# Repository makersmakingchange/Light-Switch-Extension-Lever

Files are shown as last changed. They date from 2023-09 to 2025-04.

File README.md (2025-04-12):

# Light Switch Extension Lever
The Light Switch Extension Lever is a lever designed to extend the toggle on a light switch. For some users with arthritis, limited grip strength or finger dexterity, it can be difficult to use a light switch. The Light Switch Extension Lever allows the user to flip the switch without needing any grip strength or nearly as much precision.

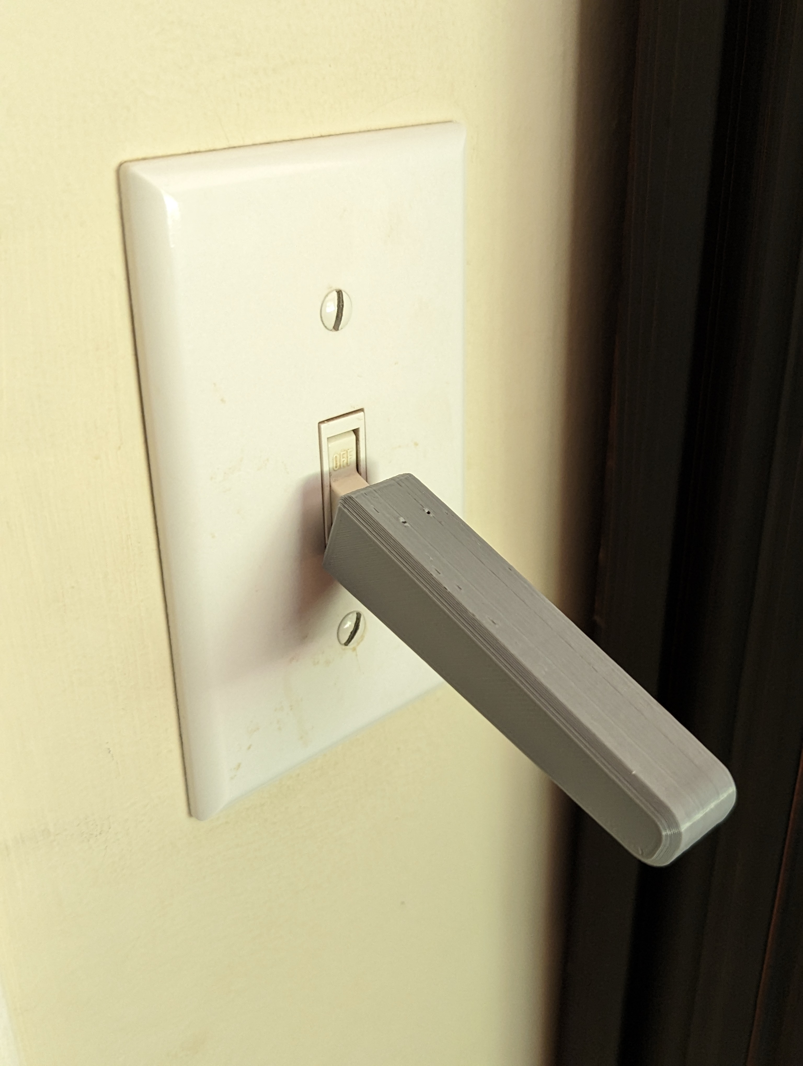
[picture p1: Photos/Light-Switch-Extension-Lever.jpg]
Picture of Light Switch Extension Lever.


## More info at
- [Makers Making Change Project Page](https://makersmakingchange.com/project/light-switch-extension-lever/)

## How to Obtain a Light Switch Extension Lever
### 1. Do it Yourself (DIY) or Do it Together (DIT)

This is an open-source assistive technology, so anyone is free to build it. All of the files and instructions required to build the device are contained within this repository. Refer to the Maker Guide below.

### 2. Request a build of this device

If you would like to obtain a Light Switch Extension Lever, you may submit a build request through the [MMC Library Page](https://makersmakingchange.com/project/light-switch-extension-lever/). The requestor is responsible for the cost of materials and any shipping.

### 3. How to build this device for someone else

If you have the skills and equipment to build this device, and would like to donate your time to create the switch for someone who needs it, visit the [MMC Maker Wanted](https://makersmakingchange.com/maker-wanted/) section.

## Getting Started

### 1. Read through the Maker Guide

The Maker Guide outlines all the different instructions for creating the device.

### 2. Print the 3D Printable components

All of the files and individual print files can be in the [/Build_Files/3D_Printing_Files](/Build_Files/3D_Printing_Files/) folder.

### 3. Assemble the Light Switch Extension Lever

Reference the [User Guide](/Documentation/Light_Switch_Extension_Lever_User_Guide_V1.0.pdf) for the tools and steps required to build each portion.

## Files
### Documentation
| Document | Version | Link |
|---|---|---|
| Design Rationale | 1.0 | [Light_Switch_Extension_Lever_Design_Rationale](/Documentation/Light_Switch_Extension_Lever_Design_Rationale_V1.0.pdf) |
| Maker Checklist | 1.0 | [Light_Switch_Extension_Lever_Maker_Checklist](/Documentation/Light_Switch_Extension_Lever_Maker_Checklist_V1.0.pdf) |
| Bill of Materials | 1.0 | [Light_Switch_Extension_Lever_Bill_of_Materials](/Documentation/Light_Switch_Extension_Lever_BOM_V1.0.xlsx) |
| 3D Printing Guide | 1.0 | [Light_Switch_Extension_Lever_3D_Printing_Guide](/Documentation/Light_Switch_Extension_Lever_3D_Printing_Guide_V1.0.pdf) |
| User Guide | 1.0 | [Light_Switch_Extension_Lever_User_Guide](/Documentation/Light_Switch_Extension_Lever_User_Guide_V1.0.pdf) |
| Changelog | 1.0 | [Light_Switch_Extension_Lever_Changelog](/Documentation/Light_Switch_Extension_Lever_Changelog_V1.0.pdf) |

### Design Files
 - [CAD Files](/Design_Files)

### Build Files
 - [3D Printing Files](/Build_Files/3D_Printing_Files)

## Attribution
Designers:
 - Initial Design by [Devon Smith](https://www.myminifactory.com/users/Devon_Smith) on [MyMiniFactory](https://www.myminifactory.com/object/3d-print-77490#google_vignette) and made available using a MyMiniFactory-Credit-Remix-Noncommercial license.
 - Further Design and Documentation by Neil Squire Society/Makers Making Change

## License
Everything needed or used to design, make, test, or prepare the Light Switch Extension Lever is licensed under the [MyMiniFactory - Credit - Remix - Noncommercial](https://www.myminifactory.com/object-licensing).

Accompanying material such as instruction manuals, videos, and other copyrightable works that are useful but not necessary to design, make, test, or prepare the Light Switch Extension Lever are published under a Creative Commons Attribution-ShareAlike 4.0 license https://creativecommons.org/licenses/by-sa/4.0/ (CC BY-SA 4.0).

---

<!-- ABOUT MMC START -->
## About Makers Making Change
[Makers Making Change Logo](https://www.makersmakingchange.com/)

Makers Making Change is a program of [Neil Squire](https://www.neilsquire.ca/), a Canadian non-profit that uses technology, knowledge, and passion to empower people with disabilities.

Makers Making Change leverages the capacity of community based Makers, Disability Professionals and Volunteers to develop and deliver affordable Open Source Assistive Technologies.

 - Website: [www.MakersMakingChange.com](https://www.makersmakingchange.com/)
 - GitHub: [makersmakingchange](https://github.com/makersmakingchange)
 - Bluesky: [@makersmakingchange.bsky.social](https://bsky.app/profile/makersmakingchange.bsky.social)
 - Instagram: [@makersmakingchange](https://www.instagram.com/makersmakingchange)
 - Facebook: [makersmakechange](https://www.facebook.com/makersmakechange)
 - LinkedIn: [Neil Squire Society](https://www.linkedin.com/company/neil-squire-society/)
 - Thingiverse: [makersmakingchange](https://www.thingiverse.com/makersmakingchange/about)
 - Printables: [MakersMakingChange](https://www.printables.com/@MakersMakingChange)

### Contact Us
For technical questions, to get involved, or to share your experience we encourage you to [visit our website](https://www.makersmakingchange.com/) or [contact us](https://www.makersmakingchange.com/s/contact).
<!-- ABOUT MMC END -->

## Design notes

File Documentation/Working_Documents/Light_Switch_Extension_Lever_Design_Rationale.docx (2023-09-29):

# Introduction

For some users with arthritis, limited grip strength or finger dexterity, it can be difficult to use a light switch. The Light Switch Extension Lever allows the user to flip the switch without needing any grip strength or nearly as much precision.

# Research

Name | Photo | Price | Link

Commercial

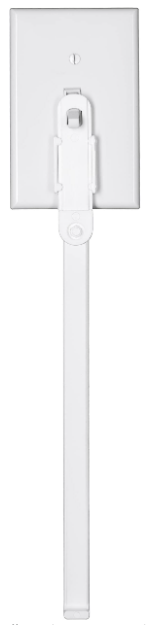
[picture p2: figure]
Amazon product image of the light switch extender for children

Light Switch Extender for Children | | $15.95 | Link (https://www.amazon.ca/Light-Switch-Extender-Children-PACK/dp/B01HHQRH96)

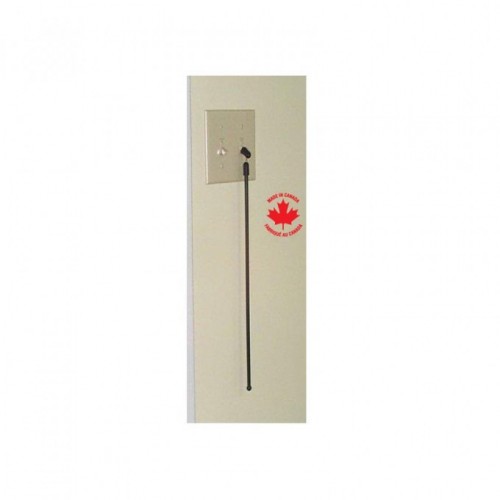
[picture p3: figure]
Image of the Light Switch Extender on a yellow white background, with a maple leaf on the wall

Light Switch Extender | | N/A | Link (https://ontariohomehealth.ca/light-switch-extender-16h165)

DIY

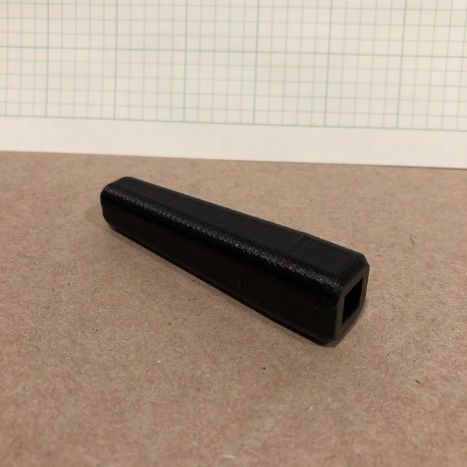
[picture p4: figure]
Light Switch Extension Lever image

Light Switch Extension Lever | | N/A | Link (https://www.myminifactory.com/object/3d-print-77490)

# Requirements

## Goals

G01 | Extend the toggle lever of a light switch so it can be toggled by bumping it with the hand

## Functional Requirements

F01 | Device must work, or be easily customizable to work with multiple thicknesses of light switch toggles

## Constraints

C01 | Must be entirely 3D printed

# Testing

The original design was tested, and found to require supports, and was too big for most of the light switches tried. It was remodeled in Fusion 360, with a changeable user parameter to accommodate any light switch.

# Opportunities for Improvement

Design could be altered to include a spring or some mechanism that would allow a one size fits all, instead of changing the Switch_Thickness parameter for each switch.

© 2023 by Neil Squire. This work is licensed under the CC BY SA 4.0 License: http://creativecommons.org/licenses/by-sa/4.0 Files available at https://github.com/makersmakingchange/light-switch-extension-lever/ Page 1 of 1

V1.0 | July 2023 Light Switch Extension Lever Design Rationale

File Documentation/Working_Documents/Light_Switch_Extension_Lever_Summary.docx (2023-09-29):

# Title

Light Switch Extension Lever

## Subtitle

The Light Switch Extension Lever allows the user to flip a light switch without needing any grip strength or nearly as much precision.

## Device Details

### Overview

For some users with arthritis, limited grip strength or finger dexterity, it can be difficult to use a light switch. The Light Switch Extension Lever allows the user to flip the switch without needing any grip strength or nearly as much precision.

### Usage

To use, place over the existing toggle switch on the light switch. The lever extends it and allows it to be bumped on and off with a hand or elbow. This works with all toggle style light switches that have a lever arm style toggle, as seen in the photo below.

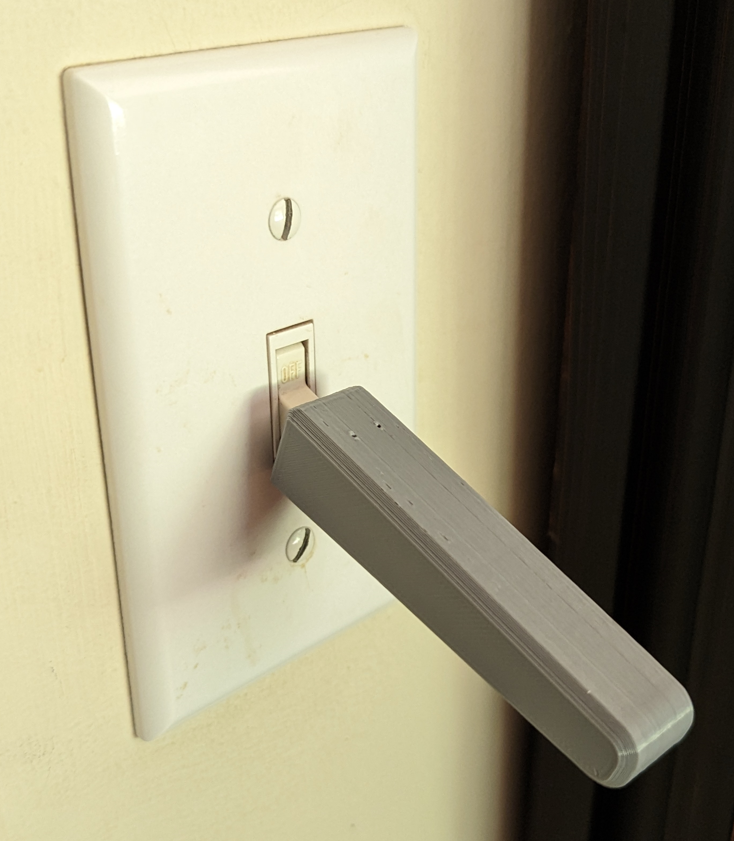
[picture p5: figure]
The light switch extender printed in grey attached to a light switch

### Cost

<$1.00

### Build Instructions

No build required, print and go.

#### Skills Required

-Basic 3D printing

#### Time Required

3D printing time: 1 hour 3 minutes

Assembly Time: <5 minutes

#### Tools

-3D printer

#### Components

-Light Switch Extension Lever.stl

### Attribution

- The Light Switch Extension Lever design (https://www.myminifactory.com/object/3d-print-77490) was created by Devon Smith (https://www.myminifactory.com/users/Devon_Smith) and made available using a MyMiniFactory-Credit-Remix-Noncommercial license.

-Further design and documentation by Neil Squire Society/Makers Making Change

© 2023 by Neil Squire. This work is licensed under the CC BY SA 4.0 License: http://creativecommons.org/licenses/by-sa/4.0 Files available at https://github.com/makersmakingchange/light-switch-extension-lever/ Page 1 of 1

V1.0 | July 2023 Light Switch Extension Lever Summary

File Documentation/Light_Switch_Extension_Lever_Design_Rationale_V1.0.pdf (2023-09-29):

V1.0 | July 2023

## Light Switch Extension Lever

## DESIGN RATIONALE

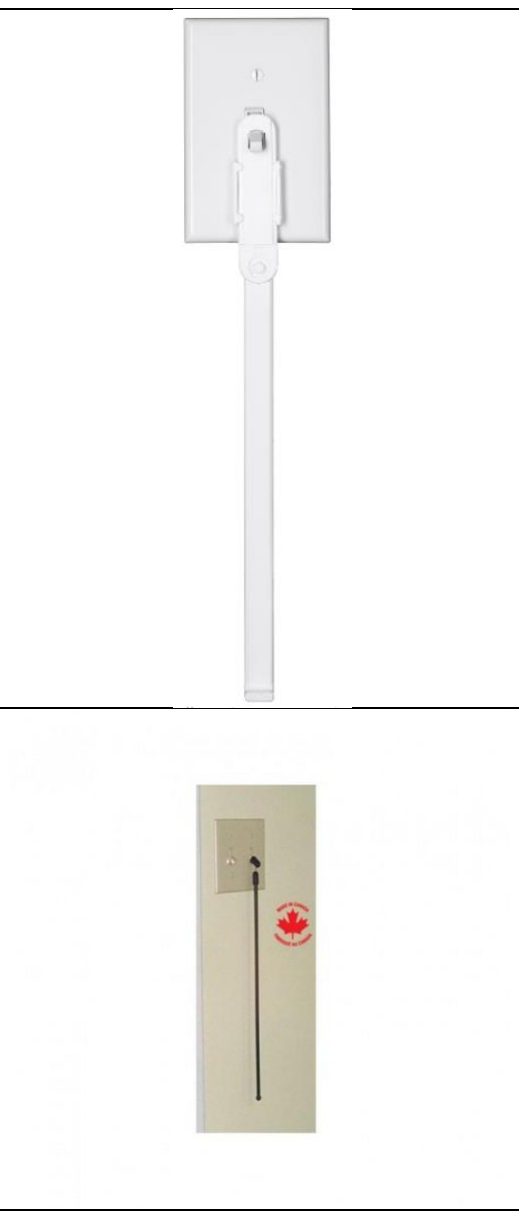
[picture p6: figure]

© 2023 by Neil Squire. (https://neilsquire.ca/)
This work is licensed under the CC BY SA 4.0 License: http://creativecommons.org/licenses/by-sa/4.0
Files available at https://github.com/makersmakingchange/light-switch-extension-lever/ | Page 1 of 2

### Introduction

For some users with arthritis, limited grip strength or finger dexterity, it can be difficult to use a light switch. The Light Switch Extension Lever allows the user to flip the switch without needing any grip strength or nearly as much precision.

### Research

Name | Photo | Price | Link
Commercial
Light Switch Extender for Children | $15.95 | Link (https://www.amazon.ca/Light-Switch-Extender-Children-PACK/dp/B01HHQRH96)
Light Switch Extender | N/A | Link (https://ontariohomehealth.ca/light-switch-extender-16h165)

DIY

V1.0 | July 2023

## Light Switch Extension Lever

## DESIGN RATIONALE

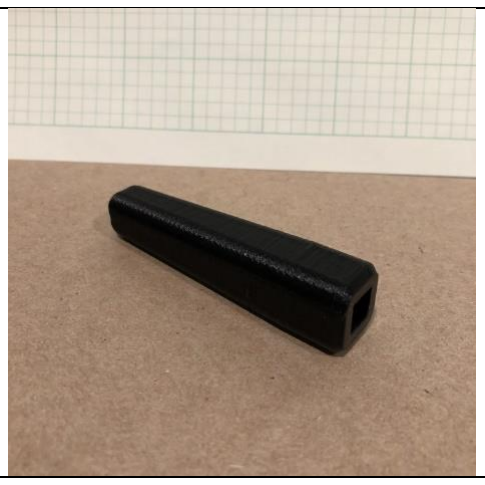
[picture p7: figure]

© 2023 by Neil Squire. (https://neilsquire.ca/)
This work is licensed under the CC BY SA 4.0 License: http://creativecommons.org/licenses/by-sa/4.0
Files available at https://github.com/makersmakingchange/light-switch-extension-lever/ | Page 2 of 2

Light Switch
Extension Lever
N/A | Link (https://www.myminifactory.com/object/3d-print-77490#google_vignette)

### Requirements

### Goals

G01 Extend the toggle lever of a light switch so it can be toggled by bumping it with the hand

### Functional Requirements

F01 Device must work, or be easily customizable to work with multiple thicknesses of light switch toggles

### Constraints

C01 Must be entirely 3D printed

### Testing

The original design was tested, and found to require supports, and was too big for most of the light switches tried. It was remodeled in Fusion 360, with a changeable user parameter to accommodate any light switch.

### Opportunities for Improvement

Design could be altered to include a spring or some mechanism that would allow a one size fits all, instead of changing the Switch_Thickness parameter for each switch.

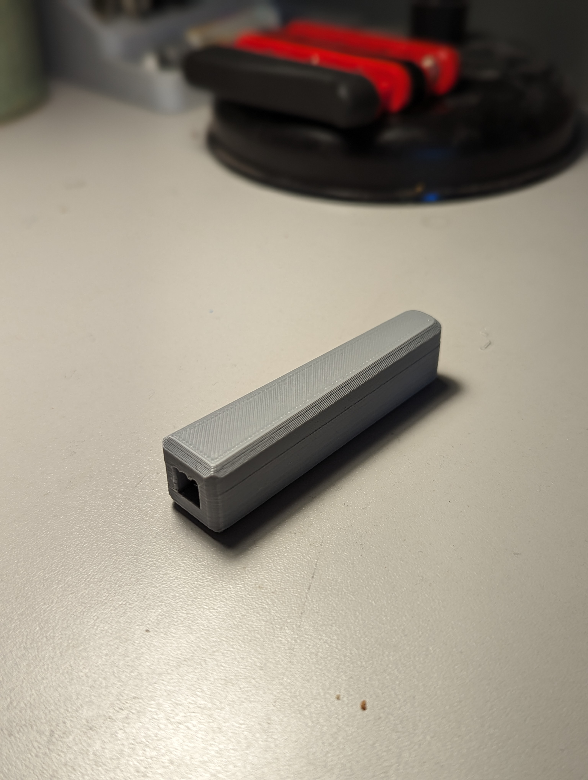
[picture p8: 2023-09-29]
Photos/Light Switch Extension Lever.stl.jpg

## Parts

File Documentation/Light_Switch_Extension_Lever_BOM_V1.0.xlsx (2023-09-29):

Light Switch Extension Lever |  | Total Cost | Total Print time (hr) | Total filament (g)
Version: V1.0 | Last Updated: 2023-Sep-18 | $0.27 | 0.00 | 9
Commercial Parts:
Part type (Electrical. Mechanical, Sanitization, ect) | Part Name | Quantity Needed | Pkg Quantity | Price per package | Price per Unit | Price for qty needed | Link
 |  |  |  |  |  | $0.00
 |  |  |  |  |  | $0.00
 |  |  |  |  |  | $0.00
3D Printed Parts ESTIMATED PRICING USING 1KG ROLL COST: | $30.00
Part | Description | Quantity Needed | TOTAL Mass (g) | Estimated Price | Print Time (Min) | Link
Light Switch Extension Lever.stl | Light Switch Extension Lever | 1 | 9 | $0.27
 |  |  |  | $0.00
 |  |  |  | $0.00
 |  |  |  | $0.00
 |  |  |  | $0.00
 |  |  | Total Print Cost: | $0.27
Tools for Assembly
Alternatives (if there are other sources for some parts link them below)
Part and description | Link

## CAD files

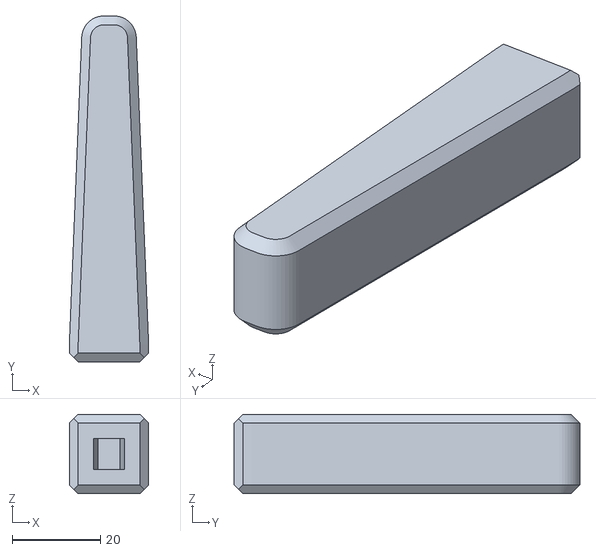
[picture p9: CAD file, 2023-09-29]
Build_Files/3D_Printing_Files/Light Switch Extension Lever.stl
18.0 x 78.5 x 18.0

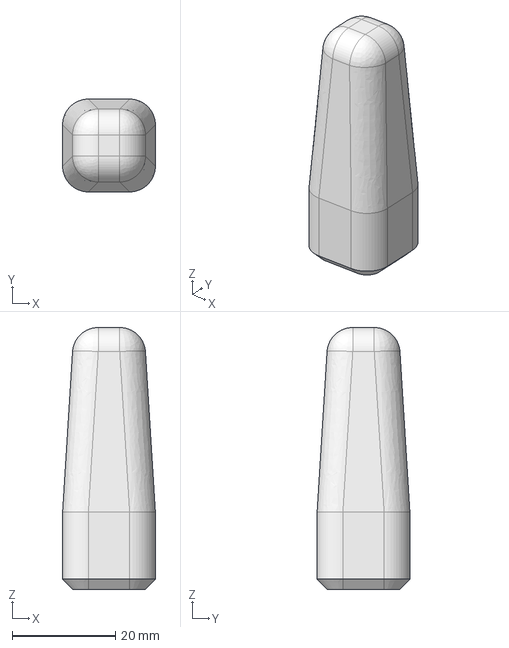
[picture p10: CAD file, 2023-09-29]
Design_Files/lightswitchextension-1.FCStd
18.0 x 18.0 x 50.8 mm

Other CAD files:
Design_Files/Light Switch Extension Lever v2.f3d

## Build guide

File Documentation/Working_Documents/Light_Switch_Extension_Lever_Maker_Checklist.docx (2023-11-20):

# Maker To Do List

- Read through the User Guide to become familiar with required components, tools, supplies, and safety gear and overall assembly steps.
- Talk to User about customization options (e.g., color, size of the light switch, any special requests, etc.)
- If required, change the Switch_Thickness parameter to accommodate the light switch
- Gather tools, supplies, and safety equipment.
- Assemble the device
- Test device
- Print “User Guide”

# Items to Give to User

- Assembled, tested device
- “User Guide”

© 2023 by Neil Squire. This work is licensed under the CC BY SA 4.0 License: http://creativecommons.org/licenses/by-sa/4.0 Files available at https://github.com/makersmakingchange/light-switch-extension-lever/ Page 1 of 1

V1.0 | July 2023 Light Switch Extension Lever Maker Checklist

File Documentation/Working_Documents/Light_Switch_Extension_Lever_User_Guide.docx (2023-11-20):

## Introduction

For some users with arthritis, limited grip strength or finger dexterity, it can be difficult to use a light switch. The Light Switch Extension Lever allows the user to flip the switch without needing any grip strength or nearly as much precision.

## Features

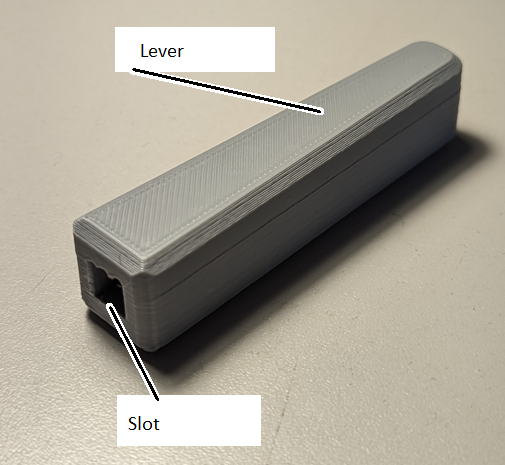
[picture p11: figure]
A photo of Light Switch Extension Lever printed in grey on a grey background with the lever and slot labeled

## Usage

To use, place the slot over the existing toggle switch on the light switch. Push it in to the point where it wedges in place on the toggle switch. The lever can then be toggled the same way as the existing switch, but with a much larger arm needing less force and less dexterity.

The extension lever printed in grey inserted over a light switch

## Compatibility

This switch extension is compatible with any toggle style light switch and has adjustable CAD parameters to accommodate any thickness of switch toggle.

## Specifications

Length: 78 mm

Thickness: 18 mm

Weight: 10 g

## Cleaning

The device can be wiped clean with a damp cloth.

© 2023 by Neil Squire. This work is licensed under the CC BY SA 4.0 License: http://creativecommons.org/licenses/by-sa/4.0 Files available at https://github.com/makersmakingchange/light-switch-extension-lever/ Page 2 of 3

V1.0 | July 2023 Light Switch Extension Lever user Quick Guide

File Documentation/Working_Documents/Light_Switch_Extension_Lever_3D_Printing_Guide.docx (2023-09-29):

# 3D Printing Summary

Metrics
Total Print Time (min) | 63
Total Number of Components | 1
Typical Total Mass (g) | 9
Typical Number of Print Setups | 1

# 3D Printing Settings

Print File Name | Qty | Total Print Time (hr:min) | Mass (g) | Infill (%) | Support(Y/N) | Layer Height/ Nozzle Diameter(mm) | Notes (orientation, special settings, etc.)
Light Switch Extension Lever.stl | 1 | 1:03 | 9 | 20 | N | 0.2/0.4 | - Print in orientation given in STL

# Customization Options

- The Fusion 360 file contains a parameter called Switch_Thickness that can be modified based on the thickness of the light switch toggle lever to help the extension lever fit better.
- The device can be printed in whatever colour the user would like.

# Examples of Quality Prints

Photos of Light Switch Extension Lever

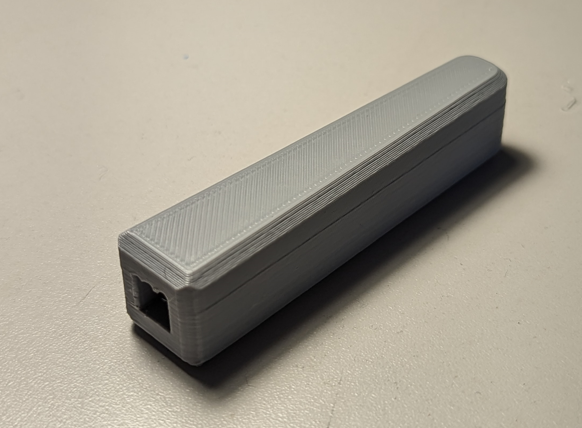
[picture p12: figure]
Quality print example of the Light Switch Extension Lever printed in grey, on a grey background

© 2023 by Neil Squire. This work is licensed under the CC BY SA 4.0 License: http://creativecommons.org/licenses/by-sa/4.0 Files available at https://github.com/makersmakingchange/light-switch-extension-lever/ Page 1 of 2

V1.0 | July 2023 Light Switch Extension Lever 3D Printing Guide

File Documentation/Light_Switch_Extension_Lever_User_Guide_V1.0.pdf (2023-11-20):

V1.0 | July 2023

## Light Switch Extension Lever

## USER QUICK GUIDE

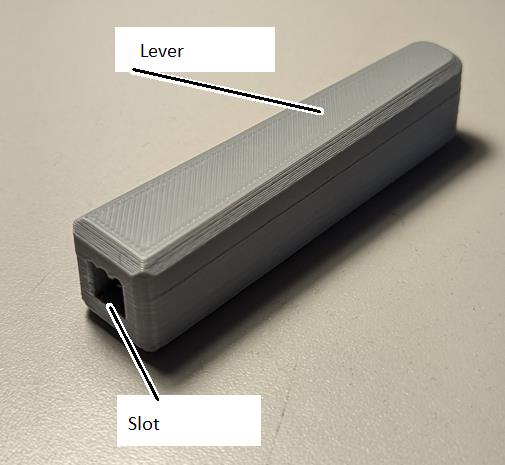
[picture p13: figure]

© 2023 by Neil Squire. (https://neilsquire.ca/)
This work is licensed under the CC BY SA 4.0 License: http://creativecommons.org/licenses/by-sa/4.0
Files available at https://github.com/makersmakingchange/light-switch-extension-lever/ | Page 1 of 2

### Introduction

For some users with arthritis, limited grip strength or finger dexterity, it can be difficult to use a light switch. The Light Switch Extension Lever allows the user to flip the switch without needing any grip strength or nearly as much precision.

### Features

V1.0 | July 2023

## Light Switch Extension Lever

## USER QUICK GUIDE

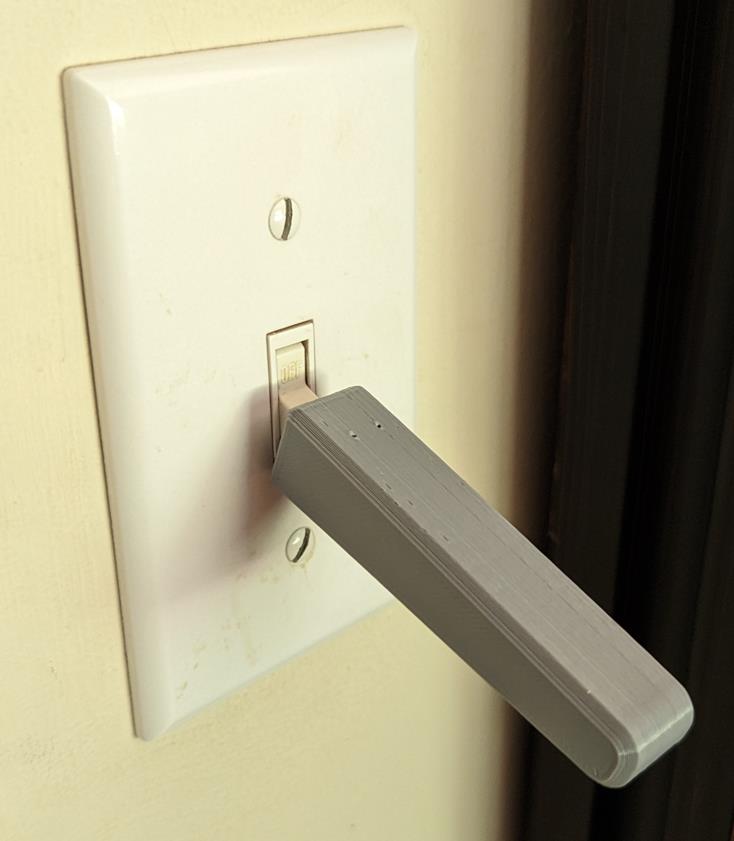
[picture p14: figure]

© 2023 by Neil Squire. (https://neilsquire.ca/)
This work is licensed under the CC BY SA 4.0 License: http://creativecommons.org/licenses/by-sa/4.0
Files available at https://github.com/makersmakingchange/light-switch-extension-lever/ | Page 2 of 2

### Usage

To use, place the slot over the existing toggle switch on the light switch. Push it in to the point where it wedges in place on the toggle switch. The lever can then be toggled the same way as the existing switch, but with a much larger arm needing less force and less dexterity.

### Compatibility

This switch extension is compatible with any toggle style light switch and has adjustable CAD parameters to accommodate any thickness of switch toggle.

### Specifications

Length: 78 mm

Thickness: 18 mm

Weight: 10 g

### Cleaning

The device can be wiped clean with a damp cloth.

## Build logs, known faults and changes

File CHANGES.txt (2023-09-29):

Version 1.0 | 2023-July-21
•	The Light Switch Extension Lever design (https://www.myminifactory.com/object/3d-print-77490) was created by Devon Smith (https://www.myminifactory.com/users/Devon_Smith) and made available using a MyMiniFactory-Credit-Remix-Noncommercial license.
•	Updated design and documentation by Neil Squire Society/Makers Making Change
